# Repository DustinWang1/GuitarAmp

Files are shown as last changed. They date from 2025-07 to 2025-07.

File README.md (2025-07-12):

# GuitarAmp
Project files for a guitar amp. Material and parts cost ~120. <br/>
Link to container CAD: https://cad.onshape.com/documents/430e134f113621e72c0b0a07/w/2a6cd6c6330c856296a7da6e/e/e5ffe4d51dda978353fd79e9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<br/>
Front top and side walls are MDF. Base is hardwood. </br>

Speaker: Celestion Eight 15</br>
Op-Amps: TL072</br>
Transistor: TIP47</br>
All potentiometers are linear. Optionally, use logarithmic taper for gain knob.</br>

Use low-ESR ceramic capacitors for bypassing. Linear potentiometers were sourced from AmplifiedParts.com.</br>

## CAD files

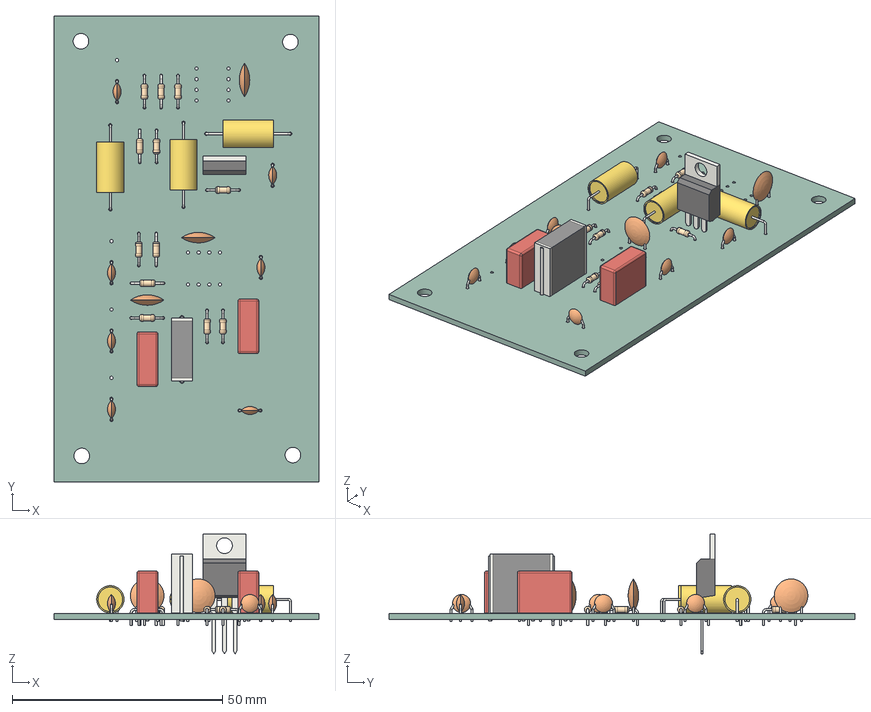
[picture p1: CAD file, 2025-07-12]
guitar_amp.step
63.0 x 110.8 x 28.5 mm
C_Disc_D4.3mm_W1.9mm_P5.00mm x 7
C_Axial_L12.0mm_D6.5mm_P20.00mm_Horizontal x 3
R_Axial_DIN0204_L3.6mm_D1.6mm_P7.62mm_Horizontal x 12
C_Disc_D8.0mm_W2.5mm_P5.00mm x 3
C_Rect_L16.5mm_W5.0mm_P15.00mm_MKT
C_Rect_L13.0mm_W5.0mm_P10.00mm_FKS3_FKP3_MKS4 x 2
TO-220-3_Vertical
guitar_amp_PCB

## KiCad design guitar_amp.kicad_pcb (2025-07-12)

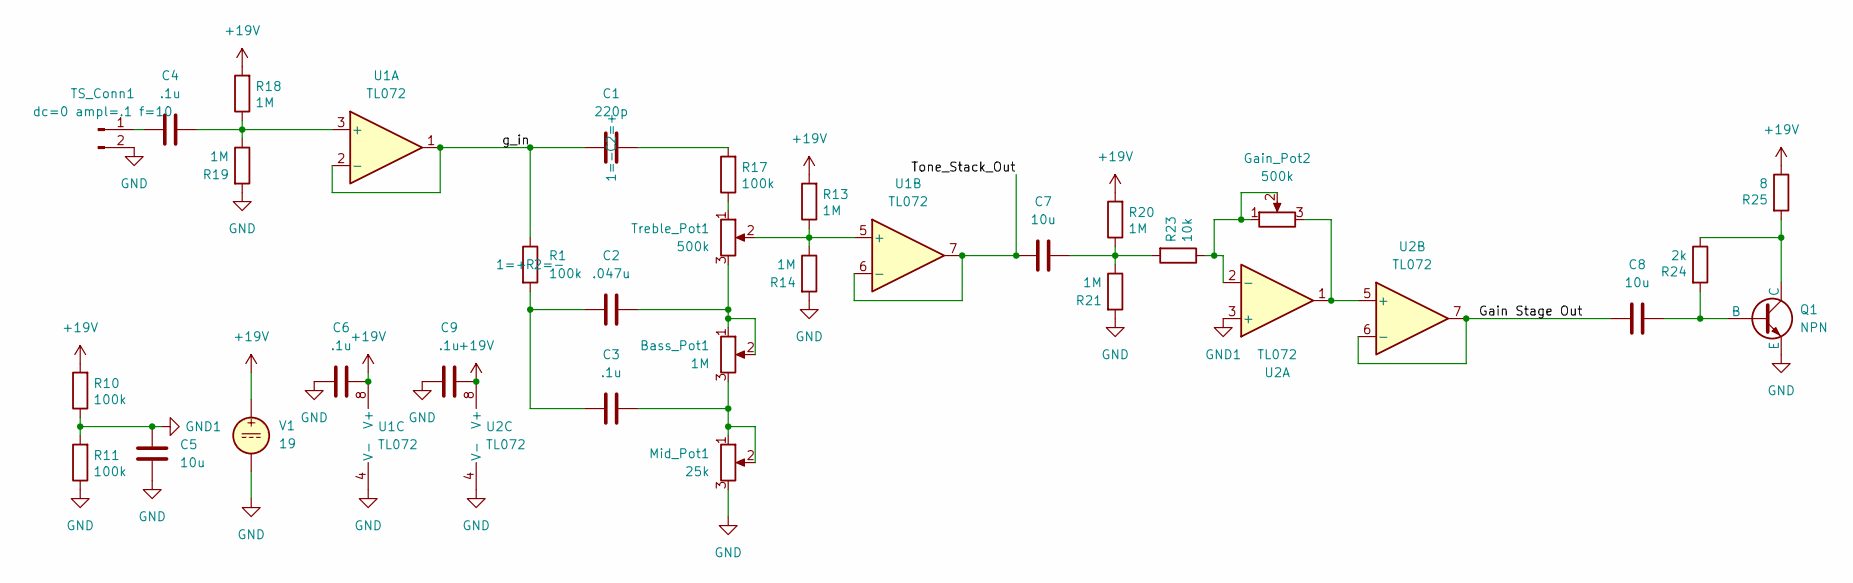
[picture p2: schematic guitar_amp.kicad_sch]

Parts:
Bass_Pot1: 1M; Screw_term_3_P5.00_1
C1: 220p; C_Disc_D8.0mm_W2.5mm_P5.00mm
C2: .047u; C_Rect_L16.5mm_W5.0mm_P15.00mm_MKT
C3, C4: .1u; C_Rect_L13.0mm_W5.0mm_P10.00mm_FKS3_FKP3_MKS4
C5, C7, C8: 10u; C_Axial_L12.0mm_D6.5mm_P20.00mm_Horizontal
C6, C9: .1u; C_Disc_D8.0mm_W2.5mm_P5.00mm
Gain_Pot2: 500k; Screw_term_3_P5.00_1
Mid_Pot1: 25k; Screw_term_3_P5.00_1
Q1: NPN; TO-220-3_Vertical
R1, R10, R11, R17: 100k; R_Axial_DIN0204_L3.6mm_D1.6mm_P7.62mm_Horizontal
R13, R14, R18, R19, R20, R21: 1M; R_Axial_DIN0204_L3.6mm_D1.6mm_P7.62mm_Horizontal
R23: 10k; R_Axial_DIN0204_L3.6mm_D1.6mm_P7.62mm_Horizontal
R24: 2k; R_Axial_DIN0204_L3.6mm_D1.6mm_P7.62mm_Horizontal
R25: 8; Screw_term_2_P5.00
TS_Conn1: dc=0 ampl=.1 f=10; Screw_term_2_P5.00
Treble_Pot1: 500k; Screw_term_3_P5.00_1
U1, U2: TL072; CERDIP-8_W7.62mm_SideBrazed_LongPads_Socket
V1: 19; Screw_term_2_P5.00

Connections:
+19V: C6.2, C9.2, R10.2, R13.2, R18.2, R20.2, R25.1, U1.8 (V+), U2.8 (V+), V1.1
/Gain Stage Out: C8.1, U2.6 (-), U2.7
/Tone_Stack_Out: C7.1, U1.6 (-), U1.7
/g_in: C1.1, R1.1, U1.1, U1.2 (-)
GND: C5.2, C6.1, C9.1, Mid_Pot1.3, Q1.3 (E), R11.1, R14.2, R19.2, R21.2, TS_Conn1.2, U1.4 (V-), U2.4 (V-), V1.2
GND1: C5.1, R10.1, R11.2, U2.3 (+)
unnamed: Bass_Pot1.1, Bass_Pot1.2, C2.2, Treble_Pot1.3
unnamed: Bass_Pot1.3, C3.2, Mid_Pot1.1, Mid_Pot1.2
unnamed: C1.2, R17.2
unnamed: C2.1, C3.1, R1.2
unnamed: C7.2, R20.1, R21.1, R23.2
unnamed: C8.2, Q1.1 (B), R24.2
unnamed: Q1.2 (C), R24.1, R25.2
unnamed: R17.1, Treble_Pot1.1
unnamed: C4.1, TS_Conn1.1
unnamed: C4.2, R18.1, R19.1, U1.3 (+)
unnamed: R13.1, R14.1, Treble_Pot1.2, U1.5 (+)
unnamed: Gain_Pot2.1, Gain_Pot2.2, R23.1, U2.2 (-)
unnamed: Gain_Pot2.3, U2.1, U2.5 (+)

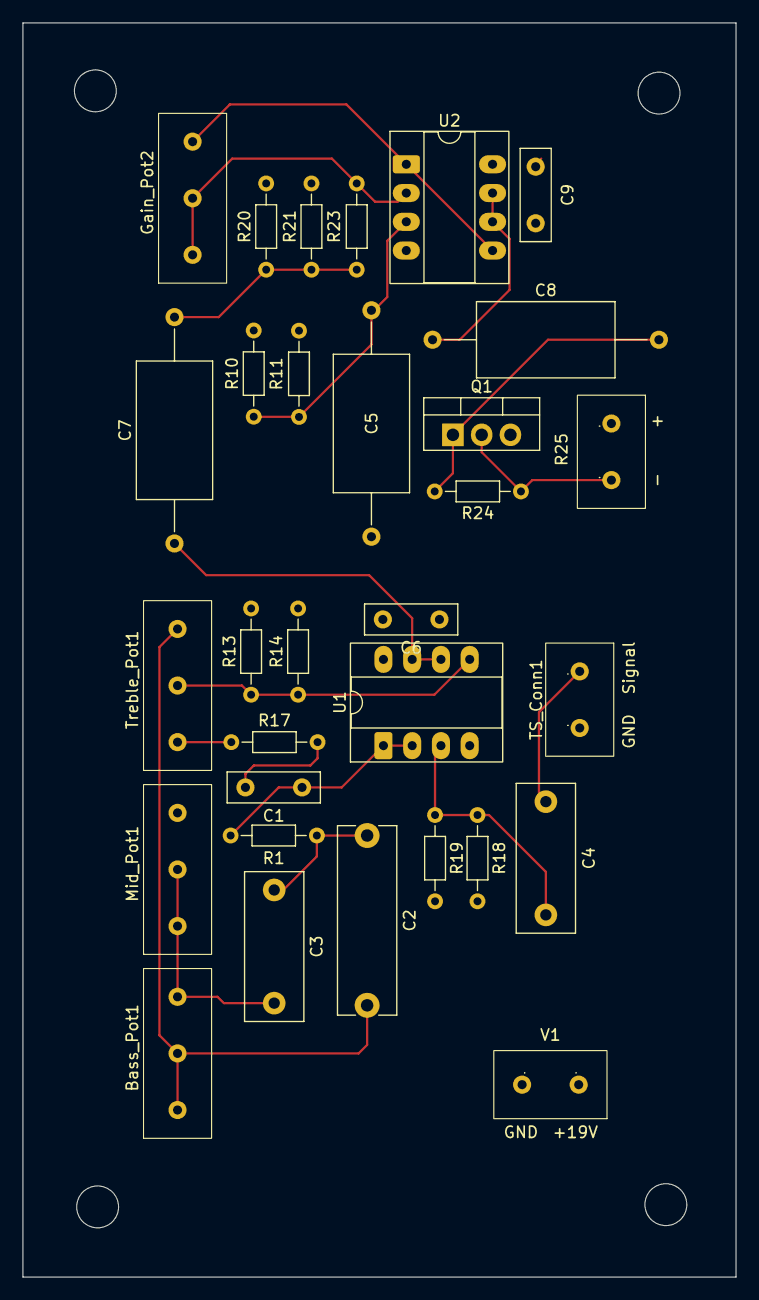
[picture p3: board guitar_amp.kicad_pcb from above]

Board: 4 copper layers, 63.0 x 110.8 mm, 31 parts (0 on the bottom side), 19 nets.
